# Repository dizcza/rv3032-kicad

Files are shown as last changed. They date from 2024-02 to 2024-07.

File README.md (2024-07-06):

# RV-3032 Kicad PCB

A replacement of the DS3231 with the same board pinout:

| DS3231 | RV3032 | Description |
|---|---|---|
| GND | GND | GND |
| VCC | VCC | 2.0-5.5V |
| SDA | SDA | I2C SDA |
| SCL | SCL | I2C SCL |
| SQW | CLKOUT | Temperature compensated square wave |
| 32K | INT | DS3231: oscillator clock; RV3032: interrupt pin |

Board dimensions: 14 x 16 mm.

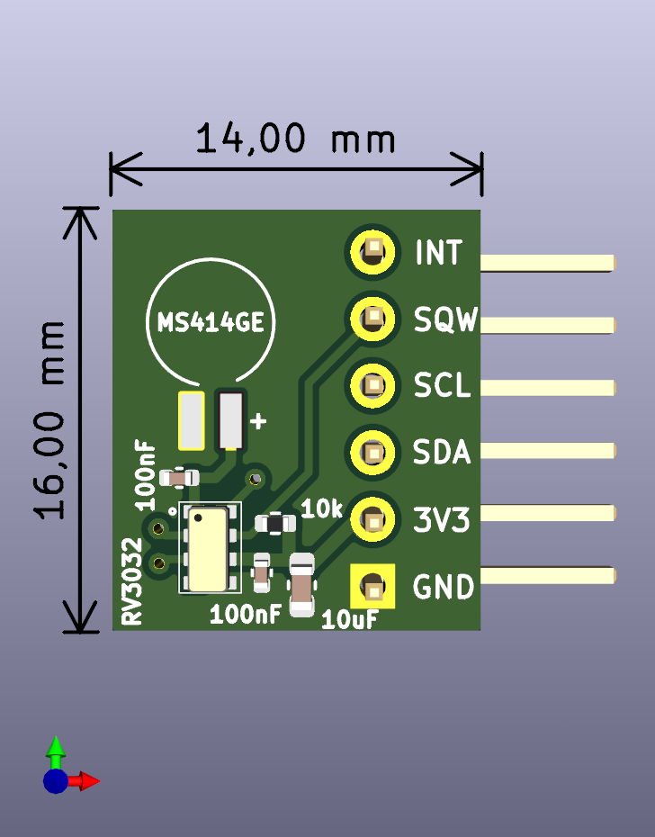
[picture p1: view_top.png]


See [schematics.pdf](./schematics.pdf).

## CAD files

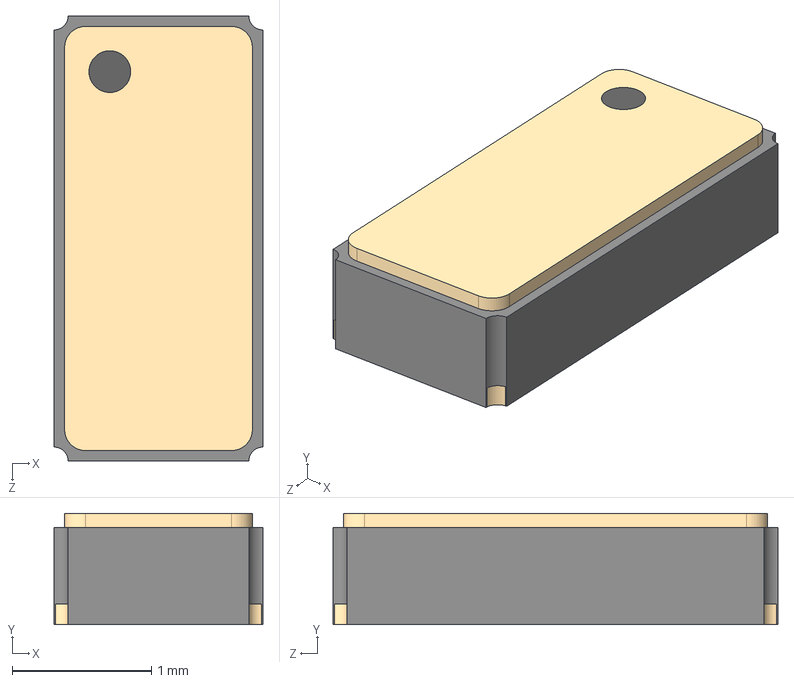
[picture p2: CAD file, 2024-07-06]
3dmodels/RV-3032-C7-32.768KHZ-3PPM-TA-QA.STEP
1.50 x 0.8 x 3.20 mm

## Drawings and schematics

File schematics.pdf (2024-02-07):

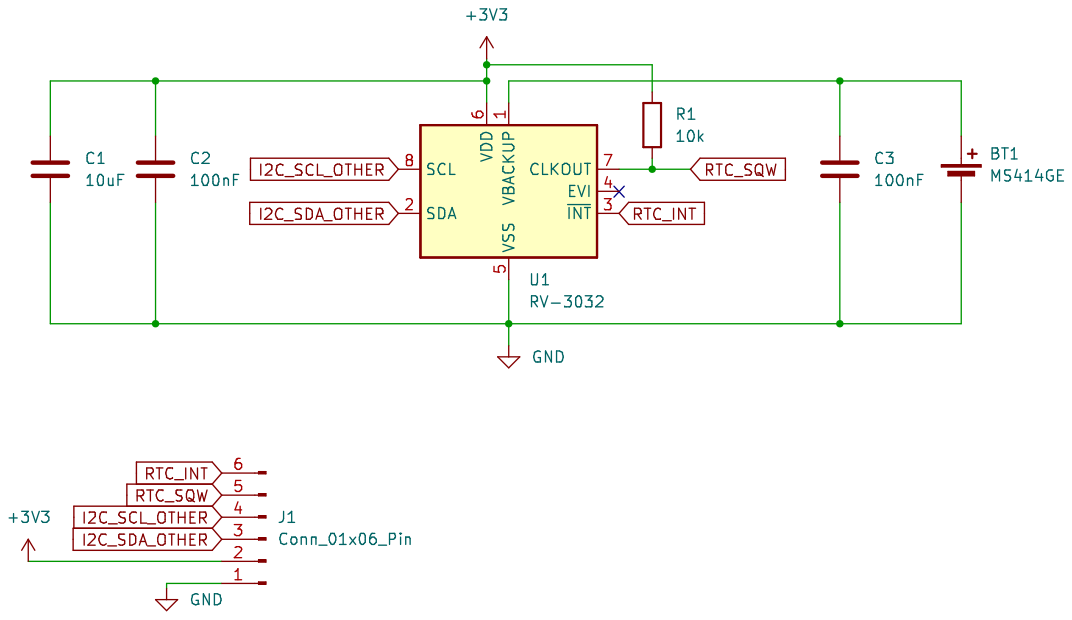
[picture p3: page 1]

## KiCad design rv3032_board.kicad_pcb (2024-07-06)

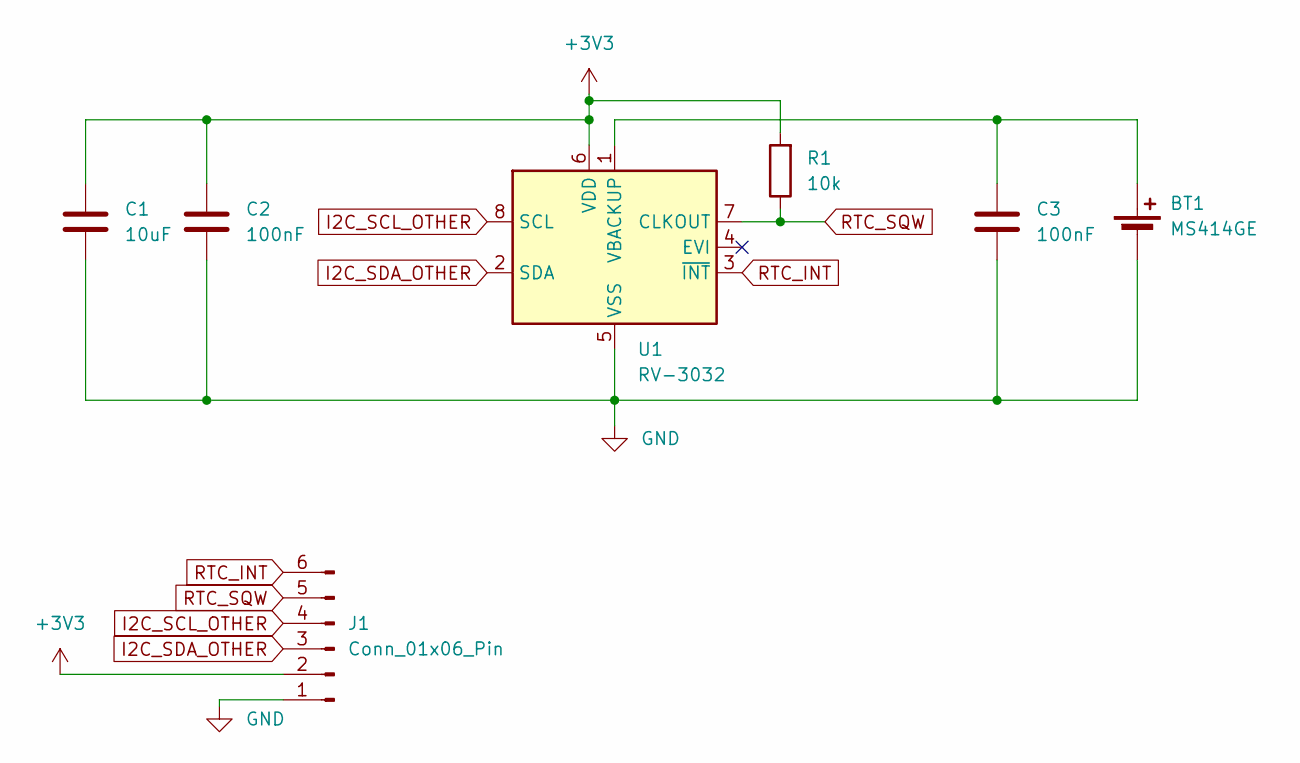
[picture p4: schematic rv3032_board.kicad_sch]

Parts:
BT1: MS414GE; BAT_MS414GE-FL26E
C1: 10uF; C_0603_1608Metric; LCSC C19702
C2, C3: 100nF; C_0402_1005Metric; LCSC C1525
J1: Conn_01x06_Pin; PinHeader_1x06_P2.54mm_Horizontal
R1: 10k; R_0402_1005Metric; LCSC C25744
U1: RV-3032; LCSC C5127802

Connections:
+3V3: C1.1, C2.2, J1.2, R1.2, U1.6 (VDD)
GND: BT1.2 (-), C1.2, C2.1, C3.1, J1.1, U1.5 (VSS)
I2C_SCL_OTHER: J1.4, U1.8 (SCL)
I2C_SDA_OTHER: J1.3, U1.2 (SDA)
unnamed: BT1.1 (+), C3.2, U1.1 (VBACKUP)
RTC_INT: J1.6, U1.3 (~INT)
RTC_SQW: J1.5, R1.1, U1.7 (CLKOUT)

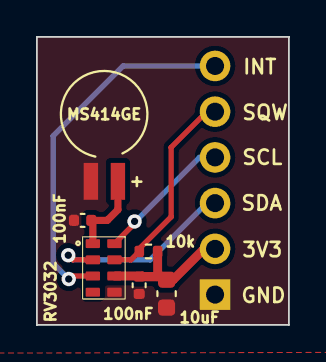
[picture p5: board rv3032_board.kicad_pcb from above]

Board: 2 copper layers, 14.0 x 16.0 mm, 7 parts (1 on the bottom side), 7 nets.

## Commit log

2024-01-28 v2: replacement DS3231
    [rv3032_board.kicad_pcb, rv3032_board.kicad_sch]
2024-02-07 v1 ordered
    [rv3032_board.kicad_pcb, rv3032_board.kicad_sch]
2024-07-06 3d model
    [RV-3032-C7-32.768KHZ-3PPM-TA-QA.STEP, rv3032_board.kicad_pcb, rv3032_board.kicad_sch]
